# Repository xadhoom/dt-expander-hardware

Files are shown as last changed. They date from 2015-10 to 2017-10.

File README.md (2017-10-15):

## Eagle schematics and board files for Detectino hardware

These are design files for two piggy back boards used in the Detectino Alarm project.

### Detectino_nodcdc
This is an expansion board used to read analog and digital inputs from commercial
alarm sensors and provide readings over a shared CAN bus.

The core is an Arduino Nano. The board provides protection for analog
and digital signals, in order to harden Arduino inputs and a CAN bus
transceiver.

Each board can handle 8 analog sensors and 3 digital ones.

Multiple boards can be connected over a single CAN bus.

### dt-expander-v2
An updated board based on Detectino_nodcdc, where the 3 digital input have been removed,
analog inputs increased from 8 to 16, 2 relays outputs have been added, along with
6 Open Collector outputs.

To accomodate all needed I/O, the board is plugged with an Arduino Mega2650 Pro Mini:
http://wiki.epalsite.com/index.php?title=Mega2560_Pro_Mini

### Detectino_raspi
This is the "core" board, which is a piggy back for RaspberryPi B+,
which provides isolated CAN bus and isolated power supply using
a suitable DC-DC converter.

The board is completely isolated from the environment, in order
to protect the RaspberryPi where the core software runs and
avoid disruption of the service caused by external electrical factors.

This board is plugged in the same CAN bus and communicate with
the Detection expansion boards-

#### Warning!
I'm not an electronic expert at all, so I tried to understand
and do my best in designing these boards.
If someone finds any error or have suggestions, please tell!

##### Notes
The other folders are initial design of the Arduino piggy back board,
not realized in practice.

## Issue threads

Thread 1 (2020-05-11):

D_OUT/X signals overlaps

xadhoom, 2020-05-11:
Maybe an older kicad bug that messed up with D_OUT/X hierarchical labels results in D_OUT/1 and /2 mixed. Same for D_OUT/4 and 5.

Newer versions of kicad disallow `/` in label names, so that may be the cause.

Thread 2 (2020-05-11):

Check symbol / package pin assignment for Q1~Q8

xadhoom, 2020-05-11:
We messed up with package / pin assignments, so Emitter got swapped with Collector :/

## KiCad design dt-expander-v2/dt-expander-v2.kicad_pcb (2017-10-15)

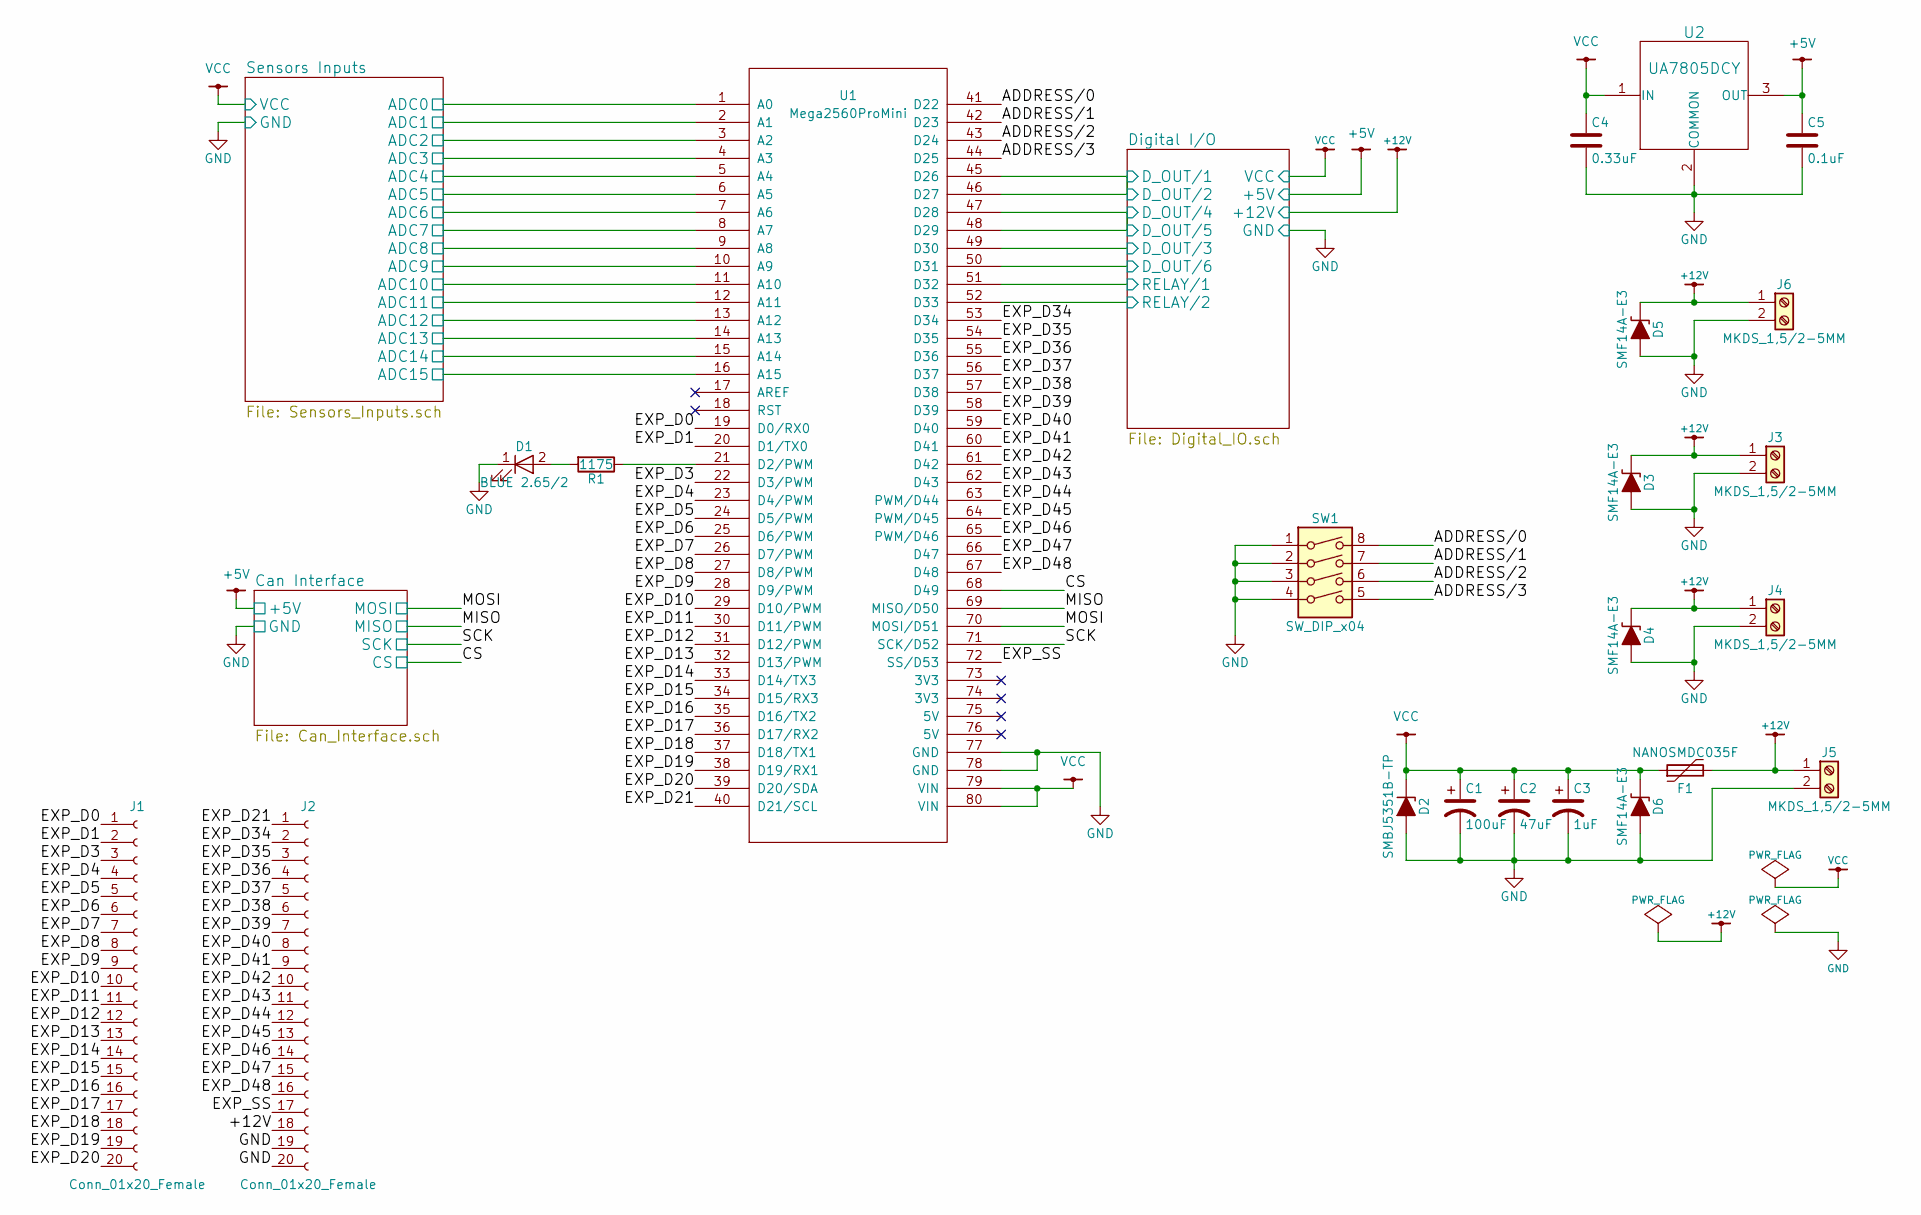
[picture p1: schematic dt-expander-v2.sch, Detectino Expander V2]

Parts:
C1: 100uF; CP_Radial_D6.3mm_P2.50mm
C2: 47uF; CP_Radial_D6.3mm_P2.50mm
C3: 1uF; CP_Radial_D4.0mm_P1.50mm
C4: 0.33uF; C_1206
C5: 0.1uF; C_1206
D1: BLUE 2.65/2; Led_1206
D2: SMBJ5351B-TP; do214aa
D3, D4, D5, D6: SMF14A-E3; do219ab
F1: NANOSMDC035F; Fuse_SMD1206_Wave
J1, J2: Conn_01x20_Female; Socket_Strip_Straight_1x20_Pitch2.54mm
J3, J4, J5, J6: MKDS_1,5/2-5MM; TerminalBlock_Pheonix_MKDS1.5-2pol
R1: 1175; R_0805
SW1: SW_DIP_x04; DIP-8_W7.62mm_LongPads
U1: Mega2560ProMini
U2: UA7805DCY; SOT-223-3Lead_TabPin2

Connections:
+5V: C5.1, U2.3 (OUT); also elsewhere on the board
+12V: D3.1 (A1), D4.1 (A1), D5.1 (A1), F1.2, J2.18, J3.1, J4.1, J5.1, J6.1; also elsewhere on the board
/ADDRESS/0: SW1.8, U1.41 (D22)
/ADDRESS/1: SW1.7, U1.42 (D23)
/ADDRESS/2: SW1.6, U1.43 (D24)
/ADDRESS/3: SW1.5, U1.44 (D25)
/CS: U1.68 (D49); also elsewhere on the board
/Digital I/O/D_OUT/1: U1.45 (D26), U1.46 (D27); also elsewhere on the board
/Digital I/O/D_OUT/3: U1.49 (D30); also elsewhere on the board
/Digital I/O/D_OUT/4: U1.47 (D28), U1.48 (D29); also elsewhere on the board
/Digital I/O/D_OUT/6: U1.50 (D31); also elsewhere on the board
/Digital I/O/RELAY/1: U1.51 (D32); also elsewhere on the board
/Digital I/O/RELAY/2: U1.52 (D33); also elsewhere on the board
/EXP_D0: J1.1, U1.19 (D0/RX0)
/EXP_D1: J1.2, U1.20 (D1/TX0)
/EXP_D3: J1.3, U1.22 (D3/PWM)
/EXP_D4: J1.4, U1.23 (D4/PWM)
/EXP_D5: J1.5, U1.24 (D5/PWM)
/EXP_D6: J1.6, U1.25 (D6/PWM)
/EXP_D7: J1.7, U1.26 (D7/PWM)
/EXP_D8: J1.8, U1.27 (D8/PWM)
/EXP_D9: J1.9, U1.28 (D9/PWM)
/EXP_D10: J1.10, U1.29 (D10/PWM)
/EXP_D11: J1.11, U1.30 (D11/PWM)
/EXP_D12: J1.12, U1.31 (D12/PWM)
/EXP_D13: J1.13, U1.32 (D13/PWM)
/EXP_D14: J1.14, U1.33 (D14/TX3)
/EXP_D15: J1.15, U1.34 (D15/RX3)
/EXP_D16: J1.16, U1.35 (D16/TX2)
/EXP_D17: J1.17, U1.36 (D17/RX2)
/EXP_D18: J1.18, U1.37 (D18/TX1)
/EXP_D19: J1.19, U1.38 (D19/RX1)
/EXP_D20: J1.20, U1.39 (D20/SDA)
/EXP_D21: J2.1, U1.40 (D21/SCL)
/EXP_D34: J2.2, U1.53 (D34)
/EXP_D35: J2.3, U1.54 (D35)
/EXP_D36: J2.4, U1.55 (D36)
/EXP_D37: J2.5, U1.56 (D37)
/EXP_D38: J2.6, U1.57 (D38)
/EXP_D39: J2.7, U1.58 (D39)
/EXP_D40: J2.8, U1.59 (D40)
/EXP_D41: J2.9, U1.60 (D41)
/EXP_D42: J2.10, U1.61 (D42)
/EXP_D43: J2.11, U1.62 (D43)
/EXP_D44: J2.12, U1.63 (PWM/D44)
/EXP_D45: J2.13, U1.64 (PWM/D45)
/EXP_D46: J2.14, U1.65 (PWM/D46)
/EXP_D47: J2.15, U1.66 (D47)
/EXP_D48: J2.16, U1.67 (D48)
/EXP_SS: J2.17, U1.72 (SS/D53)
/MISO: U1.69 (MISO/D50); also elsewhere on the board
/MOSI: U1.70 (MOSI/D51); also elsewhere on the board
/SCK: U1.71 (SCK/D52); also elsewhere on the board
/Sensors Inputs/ADC0: U1.1 (A0); also elsewhere on the board
/Sensors Inputs/ADC1: U1.2 (A1); also elsewhere on the board
/Sensors Inputs/ADC2: U1.3 (A2); also elsewhere on the board
/Sensors Inputs/ADC3: U1.4 (A3); also elsewhere on the board
/Sensors Inputs/ADC4: U1.5 (A4); also elsewhere on the board
/Sensors Inputs/ADC5: U1.6 (A5); also elsewhere on the board
/Sensors Inputs/ADC6: U1.7 (A6); also elsewhere on the board
/Sensors Inputs/ADC7: U1.8 (A7); also elsewhere on the board
/Sensors Inputs/ADC8: U1.9 (A8); also elsewhere on the board
/Sensors Inputs/ADC9: U1.10 (A9); also elsewhere on the board
/Sensors Inputs/ADC10: U1.11 (A10); also elsewhere on the board
/Sensors Inputs/ADC11: U1.12 (A11); also elsewhere on the board
/Sensors Inputs/ADC12: U1.13 (A12); also elsewhere on the board
/Sensors Inputs/ADC13: U1.14 (A13); also elsewhere on the board
/Sensors Inputs/ADC14: U1.15 (A14); also elsewhere on the board
/Sensors Inputs/ADC15: U1.16 (A15); also elsewhere on the board
GND: C1.2, C2.2, C3.2, C4.2, C5.2, D1.1 (K), D2.2 (A), D3.2 (A2), D4.2 (A2), D5.2 (A2), D6.2 (A2), J2.19, J2.20, J3.2, J4.2, J5.2, J6.2, SW1.1, SW1.2, SW1.3, SW1.4, U1.77 (GND), U1.78 (GND), U2.2 (COMMON); also elsewhere on the board
unnamed: D1.2 (A), R1.2
unnamed: R1.1, U1.21 (D2/PWM)
VCC: C1.1, C2.1, C3.1, C4.1, D2.1 (K), D6.1 (A1), F1.1, U1.79 (VIN), U1.80 (VIN), U2.1 (IN); also elsewhere on the board

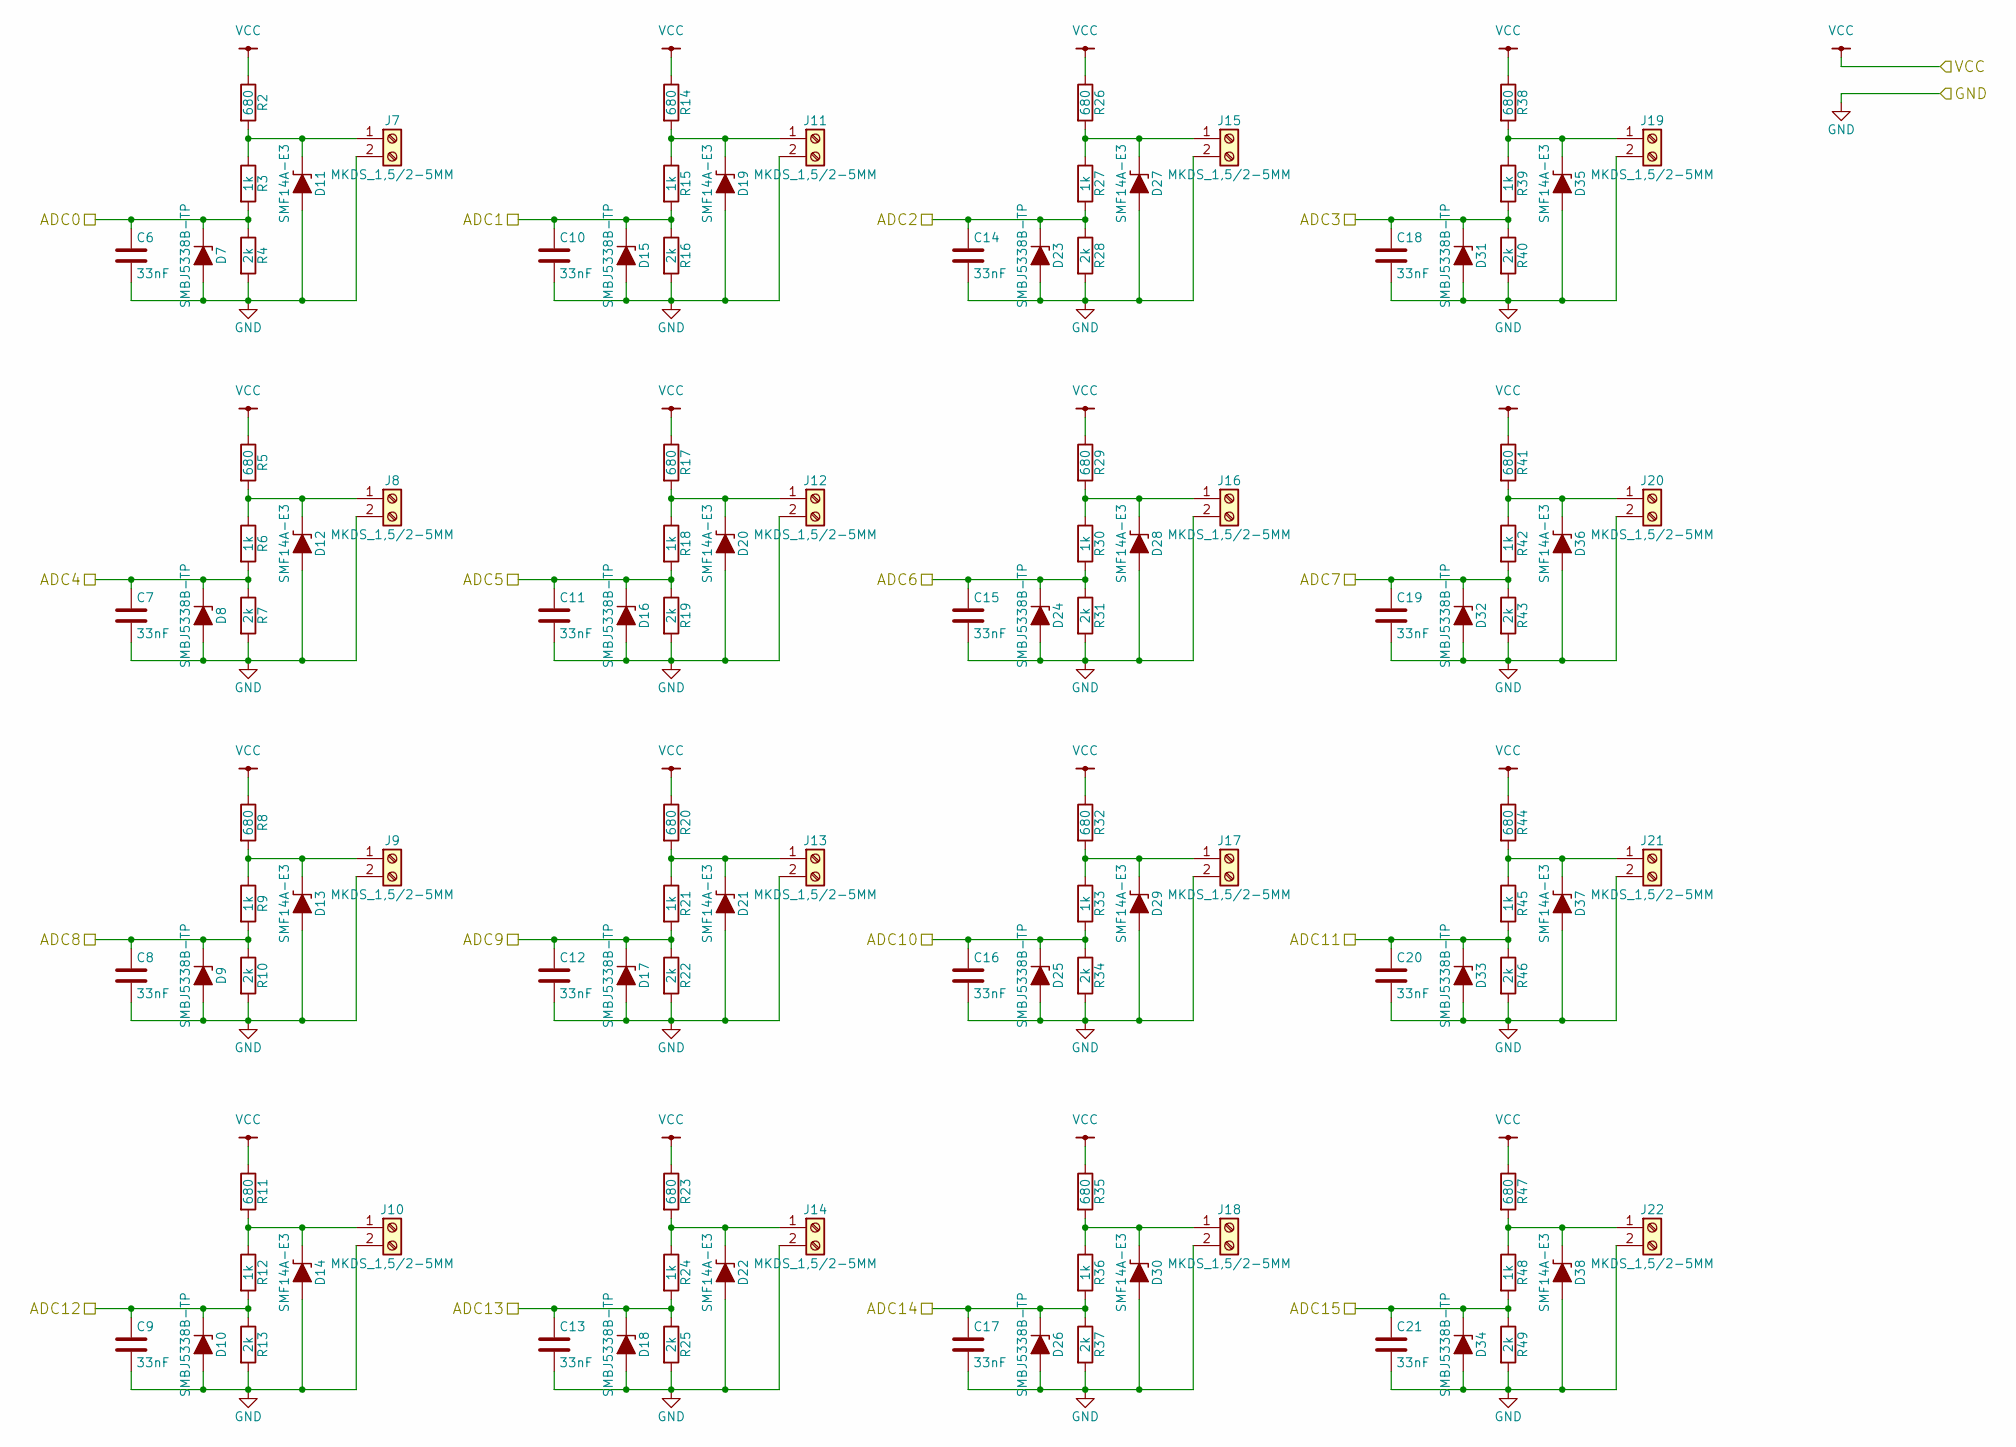
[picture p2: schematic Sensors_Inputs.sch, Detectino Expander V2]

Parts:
C6, C7, C8, C9, C10, C11, C12, C13, C14, C15, C16, C17, C18, C19, C20, C21: 33nF; C_1206
D7, D8, D9, D10, D15, D16, D17, D18, D23, D24, D25, D26, D31, D32, D33, D34: SMBJ5338B-TP; do214aa
D11, D12, D13, D14, D19, D20, D21, D22, D27, D28, D29, D30, D35, D36, D37, D38: SMF14A-E3; do219ab
J7, J8, J9, J10, J11, J12, J13, J14, J15, J16, J17, J18, J19, J20, J21, J22: MKDS_1,5/2-5MM; TerminalBlock_Pheonix_MKDS1.5-2pol
R2, R5, R8, R11, R14, R17, R20, R23, R26, R29, R32, R35, R38, R41, R44, R47: 680; R_0805
R3, R6, R9, R12, R15, R18, R21, R24, R27, R30, R33, R36, R39, R42, R45, R48: 1k; R_0805
R4, R7, R10, R13, R16, R19, R22, R25, R28, R31, R34, R37, R40, R43, R46, R49: 2k; R_0805

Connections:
/Sensors Inputs/ADC0: C6.1, D7.1 (K), R3.2, R4.1; also elsewhere on the board
/Sensors Inputs/ADC1: C10.1, D15.1 (K), R15.2, R16.1; also elsewhere on the board
/Sensors Inputs/ADC2: C14.1, D23.1 (K), R27.2, R28.1; also elsewhere on the board
/Sensors Inputs/ADC3: C18.1, D31.1 (K), R39.2, R40.1; also elsewhere on the board
/Sensors Inputs/ADC4: C7.1, D8.1 (K), R6.2, R7.1; also elsewhere on the board
/Sensors Inputs/ADC5: C11.1, D16.1 (K), R18.2, R19.1; also elsewhere on the board
/Sensors Inputs/ADC6: C15.1, D24.1 (K), R30.2, R31.1; also elsewhere on the board
/Sensors Inputs/ADC7: C19.1, D32.1 (K), R42.2, R43.1; also elsewhere on the board
/Sensors Inputs/ADC8: C8.1, D9.1 (K), R9.2, R10.1; also elsewhere on the board
/Sensors Inputs/ADC9: C12.1, D17.1 (K), R21.2, R22.1; also elsewhere on the board
/Sensors Inputs/ADC10: C16.1, D25.1 (K), R33.2, R34.1; also elsewhere on the board
/Sensors Inputs/ADC11: C20.1, D33.1 (K), R45.2, R46.1; also elsewhere on the board
/Sensors Inputs/ADC12: C9.1, D10.1 (K), R12.2, R13.1; also elsewhere on the board
/Sensors Inputs/ADC13: C13.1, D18.1 (K), R24.2, R25.1; also elsewhere on the board
/Sensors Inputs/ADC14: C17.1, D26.1 (K), R36.2, R37.1; also elsewhere on the board
/Sensors Inputs/ADC15: C21.1, D34.1 (K), R48.2, R49.1; also elsewhere on the board
GND: C6.2, C7.2, C8.2, C9.2, C10.2, C11.2, C12.2, C13.2, C14.2, C15.2, C16.2, C17.2, C18.2, C19.2, C20.2, C21.2, D7.2 (A), D8.2 (A), D9.2 (A), D10.2 (A), D11.2 (A2), D12.2 (A2), D13.2 (A2), D14.2 (A2), D15.2 (A), D16.2 (A), D17.2 (A), D18.2 (A), D19.2 (A2), D20.2 (A2), D21.2 (A2), D22.2 (A2), D23.2 (A), D24.2 (A), D25.2 (A), D26.2 (A), D27.2 (A2), D28.2 (A2), D29.2 (A2), D30.2 (A2), D31.2 (A), D32.2 (A), D33.2 (A), D34.2 (A), D35.2 (A2), D36.2 (A2), D37.2 (A2), D38.2 (A2), J7.2, J8.2, J9.2, J10.2, J11.2, J12.2, J13.2, J14.2, J15.2, J16.2, J17.2, J18.2, J19.2, J20.2, J21.2, J22.2, R4.2, R7.2, R10.2, R13.2, R16.2, R19.2, R22.2, R25.2, R28.2, R31.2, R34.2, R37.2, R40.2, R43.2, R46.2, R49.2; also elsewhere on the board
unnamed 82: D11.1 (A1), J7.1, R2.2, R3.1; also elsewhere on the board
unnamed 83: D12.1 (A1), J8.1, R5.2, R6.1; also elsewhere on the board
unnamed 84: D13.1 (A1), J9.1, R8.2, R9.1; also elsewhere on the board
unnamed 85: D14.1 (A1), J10.1, R11.2, R12.1; also elsewhere on the board
unnamed 86: D19.1 (A1), J11.1, R14.2, R15.1; also elsewhere on the board
unnamed 87: D20.1 (A1), J12.1, R17.2, R18.1; also elsewhere on the board
unnamed 88: D21.1 (A1), J13.1, R20.2, R21.1; also elsewhere on the board
unnamed 89: D22.1 (A1), J14.1, R23.2, R24.1; also elsewhere on the board
unnamed 90: D27.1 (A1), J15.1, R26.2, R27.1; also elsewhere on the board
unnamed 91: D28.1 (A1), J16.1, R29.2, R30.1; also elsewhere on the board
unnamed 92: D29.1 (A1), J17.1, R32.2, R33.1; also elsewhere on the board
unnamed 93: D30.1 (A1), J18.1, R35.2, R36.1; also elsewhere on the board
unnamed 94: D35.1 (A1), J19.1, R38.2, R39.1; also elsewhere on the board
unnamed 95: D36.1 (A1), J20.1, R41.2, R42.1; also elsewhere on the board
unnamed 96: D37.1 (A1), J21.1, R44.2, R45.1; also elsewhere on the board
unnamed 97: D38.1 (A1), J22.1, R47.2, R48.1; also elsewhere on the board
VCC: R2.1, R5.1, R8.1, R11.1, R14.1, R17.1, R20.1, R23.1, R26.1, R29.1, R32.1, R35.1, R38.1, R41.1, R44.1, R47.1; also elsewhere on the board

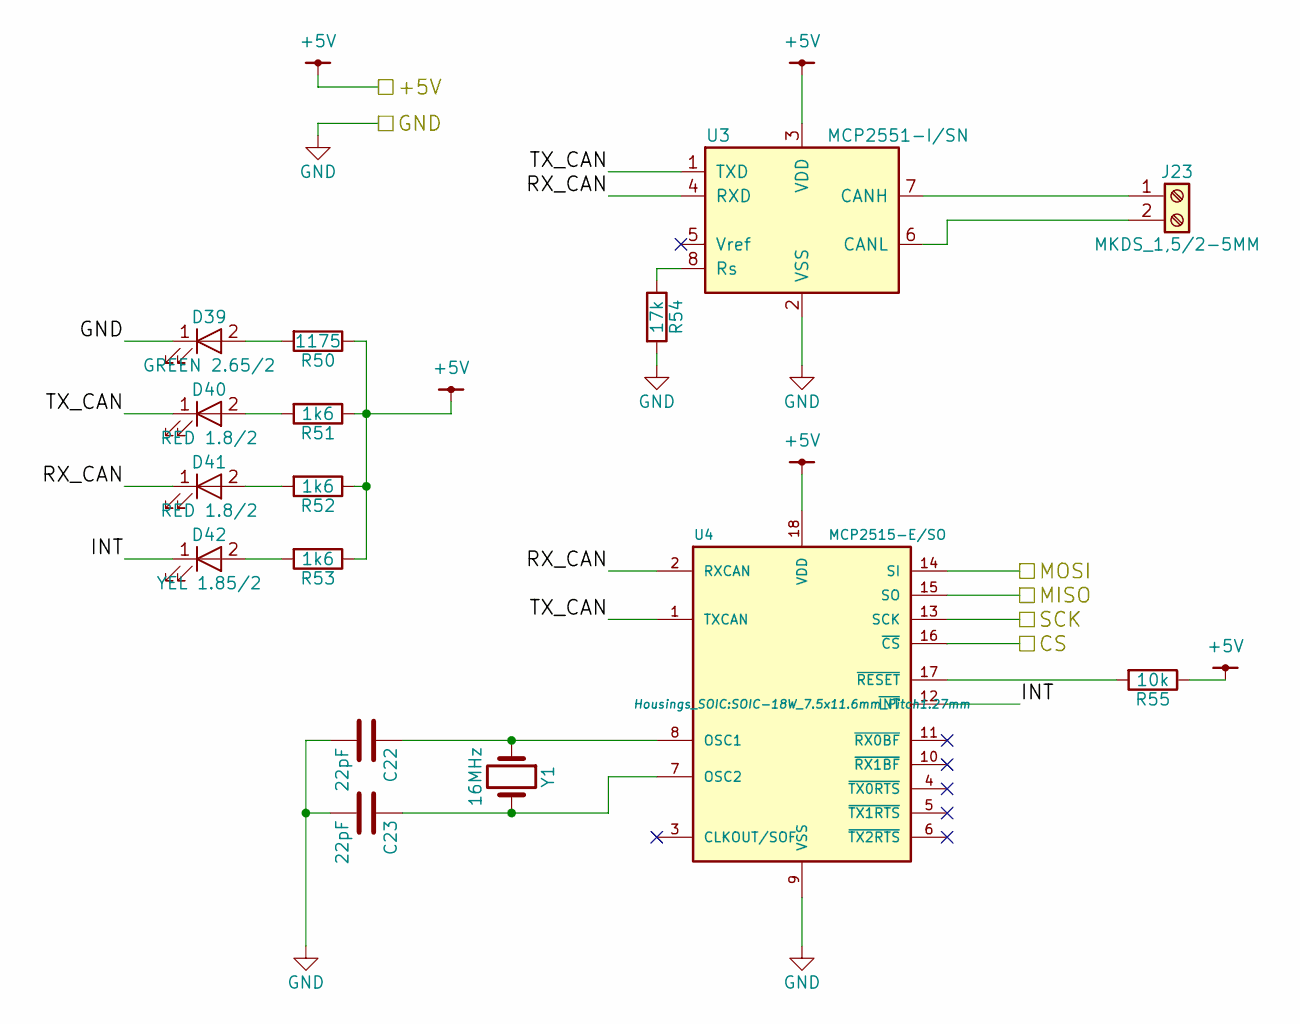
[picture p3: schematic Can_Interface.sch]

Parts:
C22, C23: 22pF; C_1206
D39: GREEN 2.65/2; Led_1206
D40, D41: RED 1.8/2; Led_1206
D42: YEL 1.85/2; Led_1206
J23: MKDS_1,5/2-5MM; TerminalBlock_Pheonix_MKDS1.5-2pol
R50: 1175; R_0805
R51, R52, R53: 1k6; R_0805
R54: 17k; R_0805
R55: 10k; R_0805
U3: MCP2551-I/SN; SOIC-8_3.9x4.9mm_Pitch1.27mm
U4: MCP2515-E/SO; SOIC-18W_7.5x11.6mm_Pitch1.27mm
Y1: 16MHz; Crystal_HC49-U_Vertical

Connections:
+5V: R50.1, R51.1, R52.1, R53.1, R55.1, U3.3 (VDD), U4.18 (VDD); also elsewhere on the board
/CS: U4.16 (~CS~); also elsewhere on the board
/Can Interface/INT: D42.1 (K), U4.12 (~INT~)
/Can Interface/RX_CAN: D41.1 (K), U3.4 (RXD), U4.2 (RXCAN)
/Can Interface/TX_CAN: D40.1 (K), U3.1 (TXD), U4.1 (TXCAN)
/MISO: U4.15 (SO); also elsewhere on the board
/MOSI: U4.14 (SI); also elsewhere on the board
/SCK: U4.13 (SCK); also elsewhere on the board
GND: C22.2, C23.2, D39.1 (K), R54.2, U3.2 (VSS), U4.9 (VSS); also elsewhere on the board
unnamed: C22.1, U4.8 (OSC1), Y1.1
unnamed: C23.1, U4.7 (OSC2), Y1.2
unnamed: D39.2 (A), R50.2
unnamed: D40.2 (A), R51.2
unnamed: D41.2 (A), R52.2
unnamed: D42.2 (A), R53.2
unnamed: J23.1, U3.7 (CANH)
unnamed: J23.2, U3.6 (CANL)
unnamed: R54.1, U3.8 (Rs)
unnamed: R55.2, U4.17 (~RESET~)

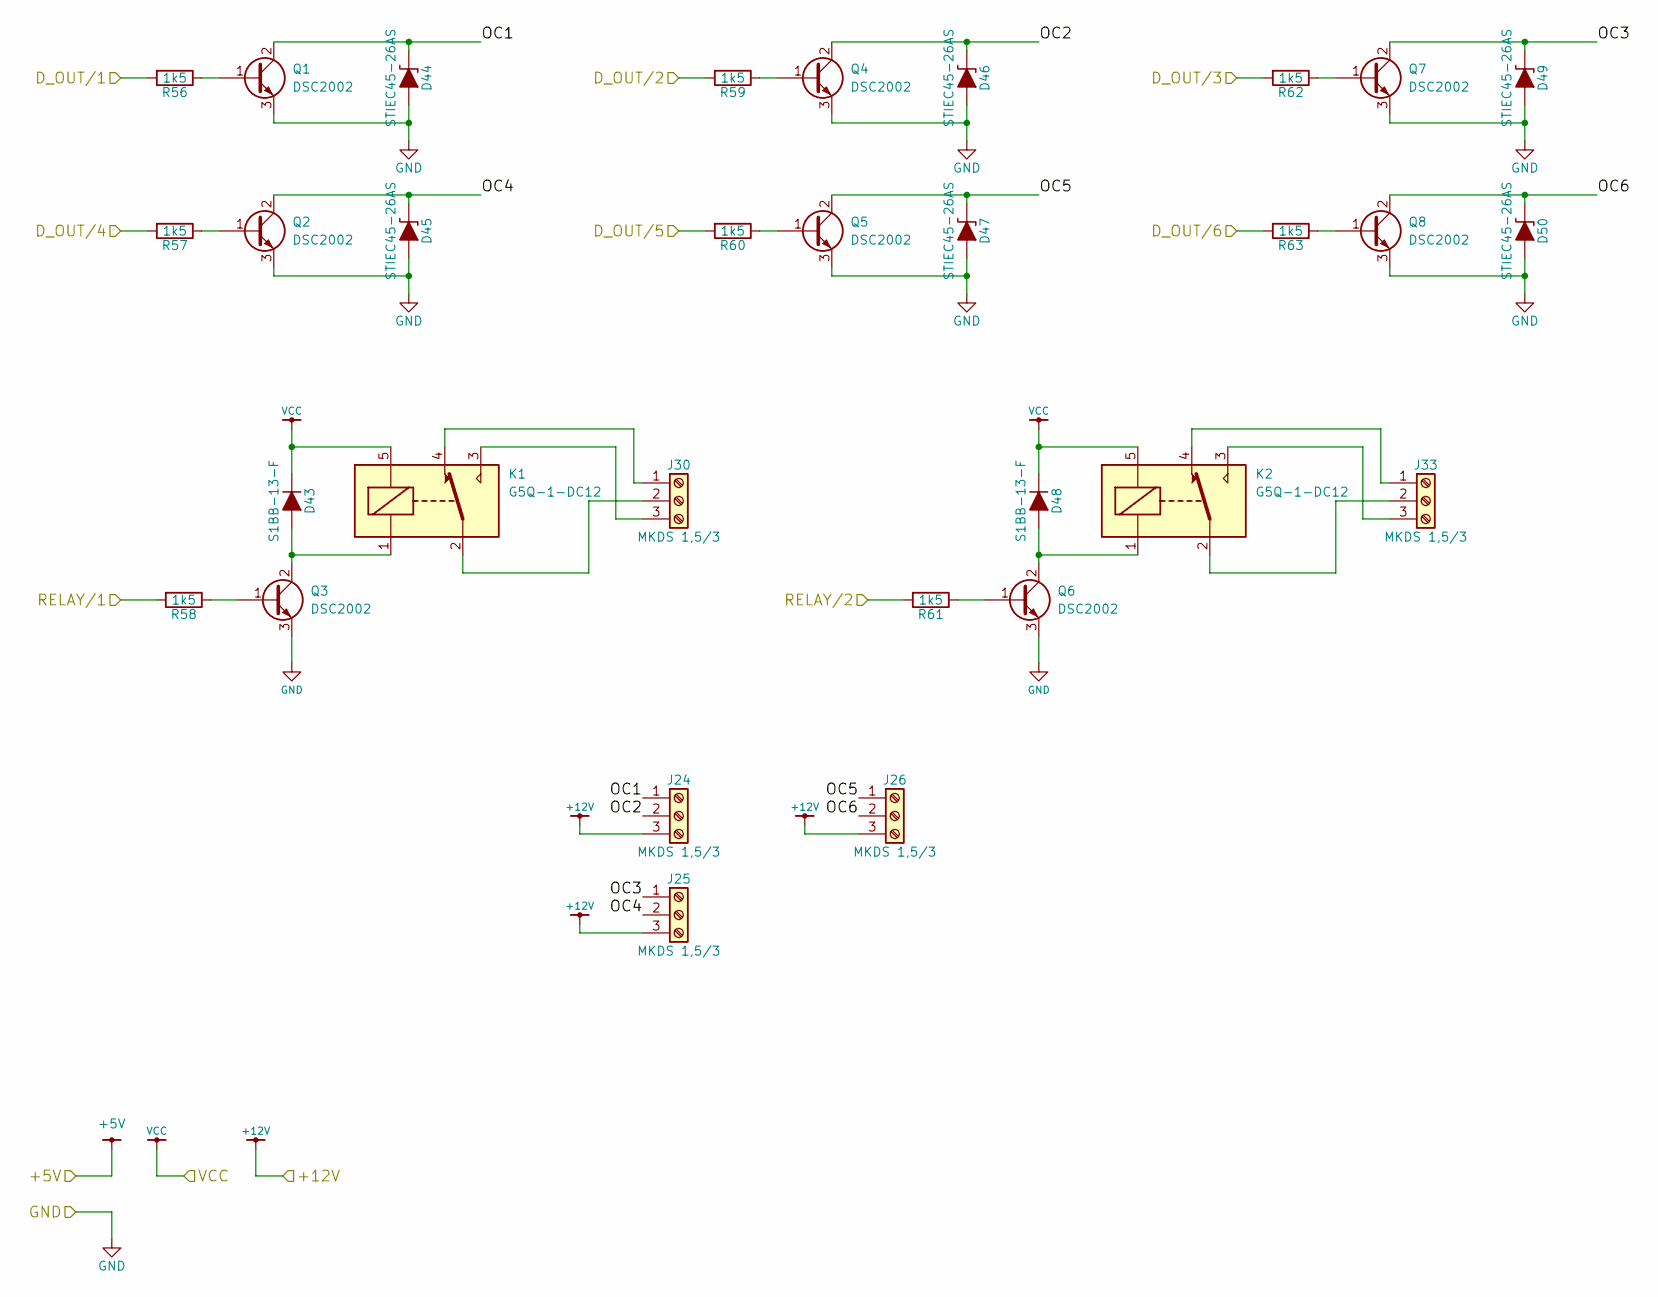
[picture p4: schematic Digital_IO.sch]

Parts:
D43, D48: S1BB-13-F; do214aa
D44, D45, D46, D47, D49, D50: STIEC45-26AS; do214ab
J24, J25, J26, J30, J33: MKDS 1,5/3; TerminalBlock_Pheonix_MKDS1.5-3pol
K1, K2: G5Q-1-DC12; Relay_SPDT_OMRON-G5Q
Q1, Q2, Q3, Q4, Q5, Q6, Q7, Q8: DSC2002; SOT-23
R56, R57, R58, R59, R60, R61, R62, R63: 1k5; R_0805

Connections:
+12V: J24.3, J25.3, J26.3; also elsewhere on the board
/Digital I/O/D_OUT/1: R56.2, R59.2; also elsewhere on the board
/Digital I/O/D_OUT/3: R62.2; also elsewhere on the board
/Digital I/O/D_OUT/4: R57.2, R60.2; also elsewhere on the board
/Digital I/O/D_OUT/6: R63.2; also elsewhere on the board
/Digital I/O/OC1: D44.1 (A1), J24.1, Q1.2 (C)
/Digital I/O/OC2: D46.1 (A1), J24.2, Q4.2 (C)
/Digital I/O/OC3: D49.1 (A1), J25.1, Q7.2 (C)
/Digital I/O/OC4: D45.1 (A1), J25.2, Q2.2 (C)
/Digital I/O/OC5: D47.1 (A1), J26.1, Q5.2 (C)
/Digital I/O/OC6: D50.1 (A1), J26.2, Q8.2 (C)
/Digital I/O/RELAY/1: R58.2; also elsewhere on the board
/Digital I/O/RELAY/2: R61.2; also elsewhere on the board
GND: D44.2 (A2), D45.2 (A2), D46.2 (A2), D47.2 (A2), D49.2 (A2), D50.2 (A2), Q1.3 (E), Q2.3 (E), Q3.3 (E), Q4.3 (E), Q5.3 (E), Q6.3 (E), Q7.3 (E), Q8.3 (E); also elsewhere on the board
unnamed: D43.2 (A), K1.1, Q3.2 (C)
unnamed: D48.2 (A), K2.1, Q6.2 (C)
unnamed: J30.1, K1.4
unnamed: J30.2, K1.2
unnamed: J30.3, K1.3
unnamed: J33.1, K2.4
unnamed: J33.2, K2.2
unnamed: J33.3, K2.3
unnamed: Q1.1 (B), R56.1
unnamed: Q2.1 (B), R57.1
unnamed: Q3.1 (B), R58.1
unnamed: Q4.1 (B), R59.1
unnamed: Q5.1 (B), R60.1
unnamed: Q6.1 (B), R61.1
unnamed: Q7.1 (B), R62.1
unnamed: Q8.1 (B), R63.1
VCC: D43.1 (K), D48.1 (K), K1.5, K2.5; also elsewhere on the board

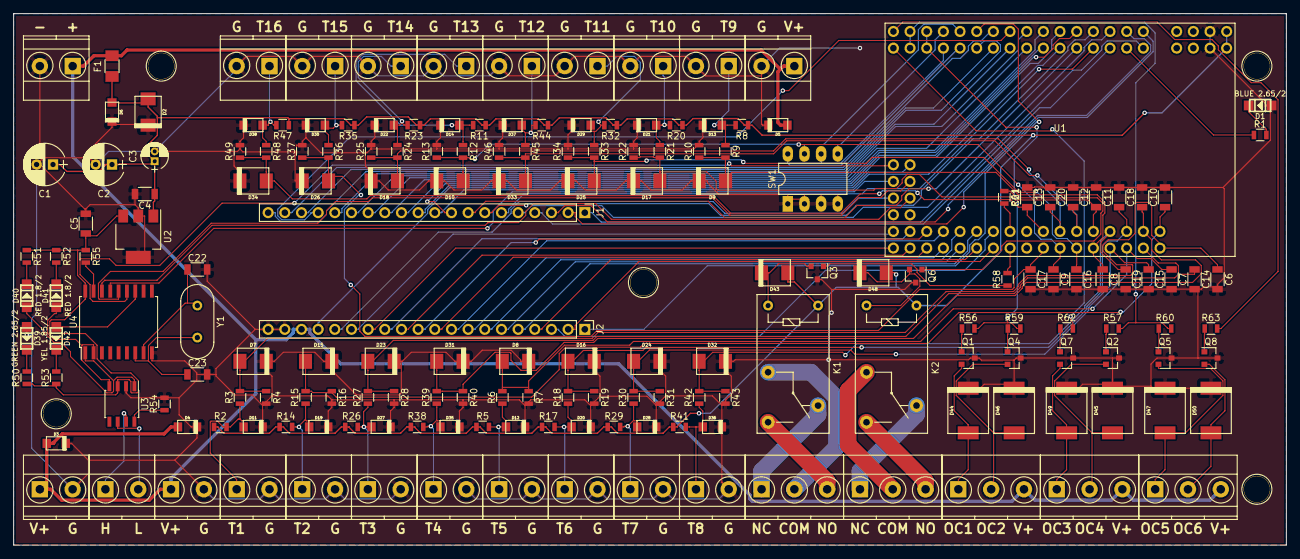
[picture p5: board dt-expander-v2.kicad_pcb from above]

Board: 2 copper layers, 194.0 x 81.0 mm, 185 parts (0 on the bottom side), 124 nets.

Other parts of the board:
HOLE1, HOLE2, HOLE3, HOLE4: 1pin
T1, T2, T3, T4, T5, T6, T7, T8, T9, T10, T11, T12, T13, T14, T15, T16: MKDS_1,5/2-5MM; TerminalBlock_Pheonix_MKDS1.5-2pol

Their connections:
GND: T1.2, T2.2, T3.2, T4.2, T5.2, T6.2, T7.2, T8.2, T9.2, T10.2, T11.2, T12.2, T13.2, T14.2, T15.2, T16.2; also elsewhere on the board
unnamed 82: T1.1; also elsewhere on the board
unnamed 83: T5.1; also elsewhere on the board
unnamed 84: T9.1; also elsewhere on the board
unnamed 85: T13.1; also elsewhere on the board
unnamed 86: T2.1; also elsewhere on the board
unnamed 87: T6.1; also elsewhere on the board
unnamed 88: T10.1; also elsewhere on the board
unnamed 89: T14.1; also elsewhere on the board
unnamed 90: T3.1; also elsewhere on the board
unnamed 91: T7.1; also elsewhere on the board
unnamed 92: T11.1; also elsewhere on the board
unnamed 93: T15.1; also elsewhere on the board
unnamed 94: T4.1; also elsewhere on the board
unnamed 95: T8.1; also elsewhere on the board
unnamed 96: T12.1; also elsewhere on the board
unnamed 97: T16.1; also elsewhere on the board

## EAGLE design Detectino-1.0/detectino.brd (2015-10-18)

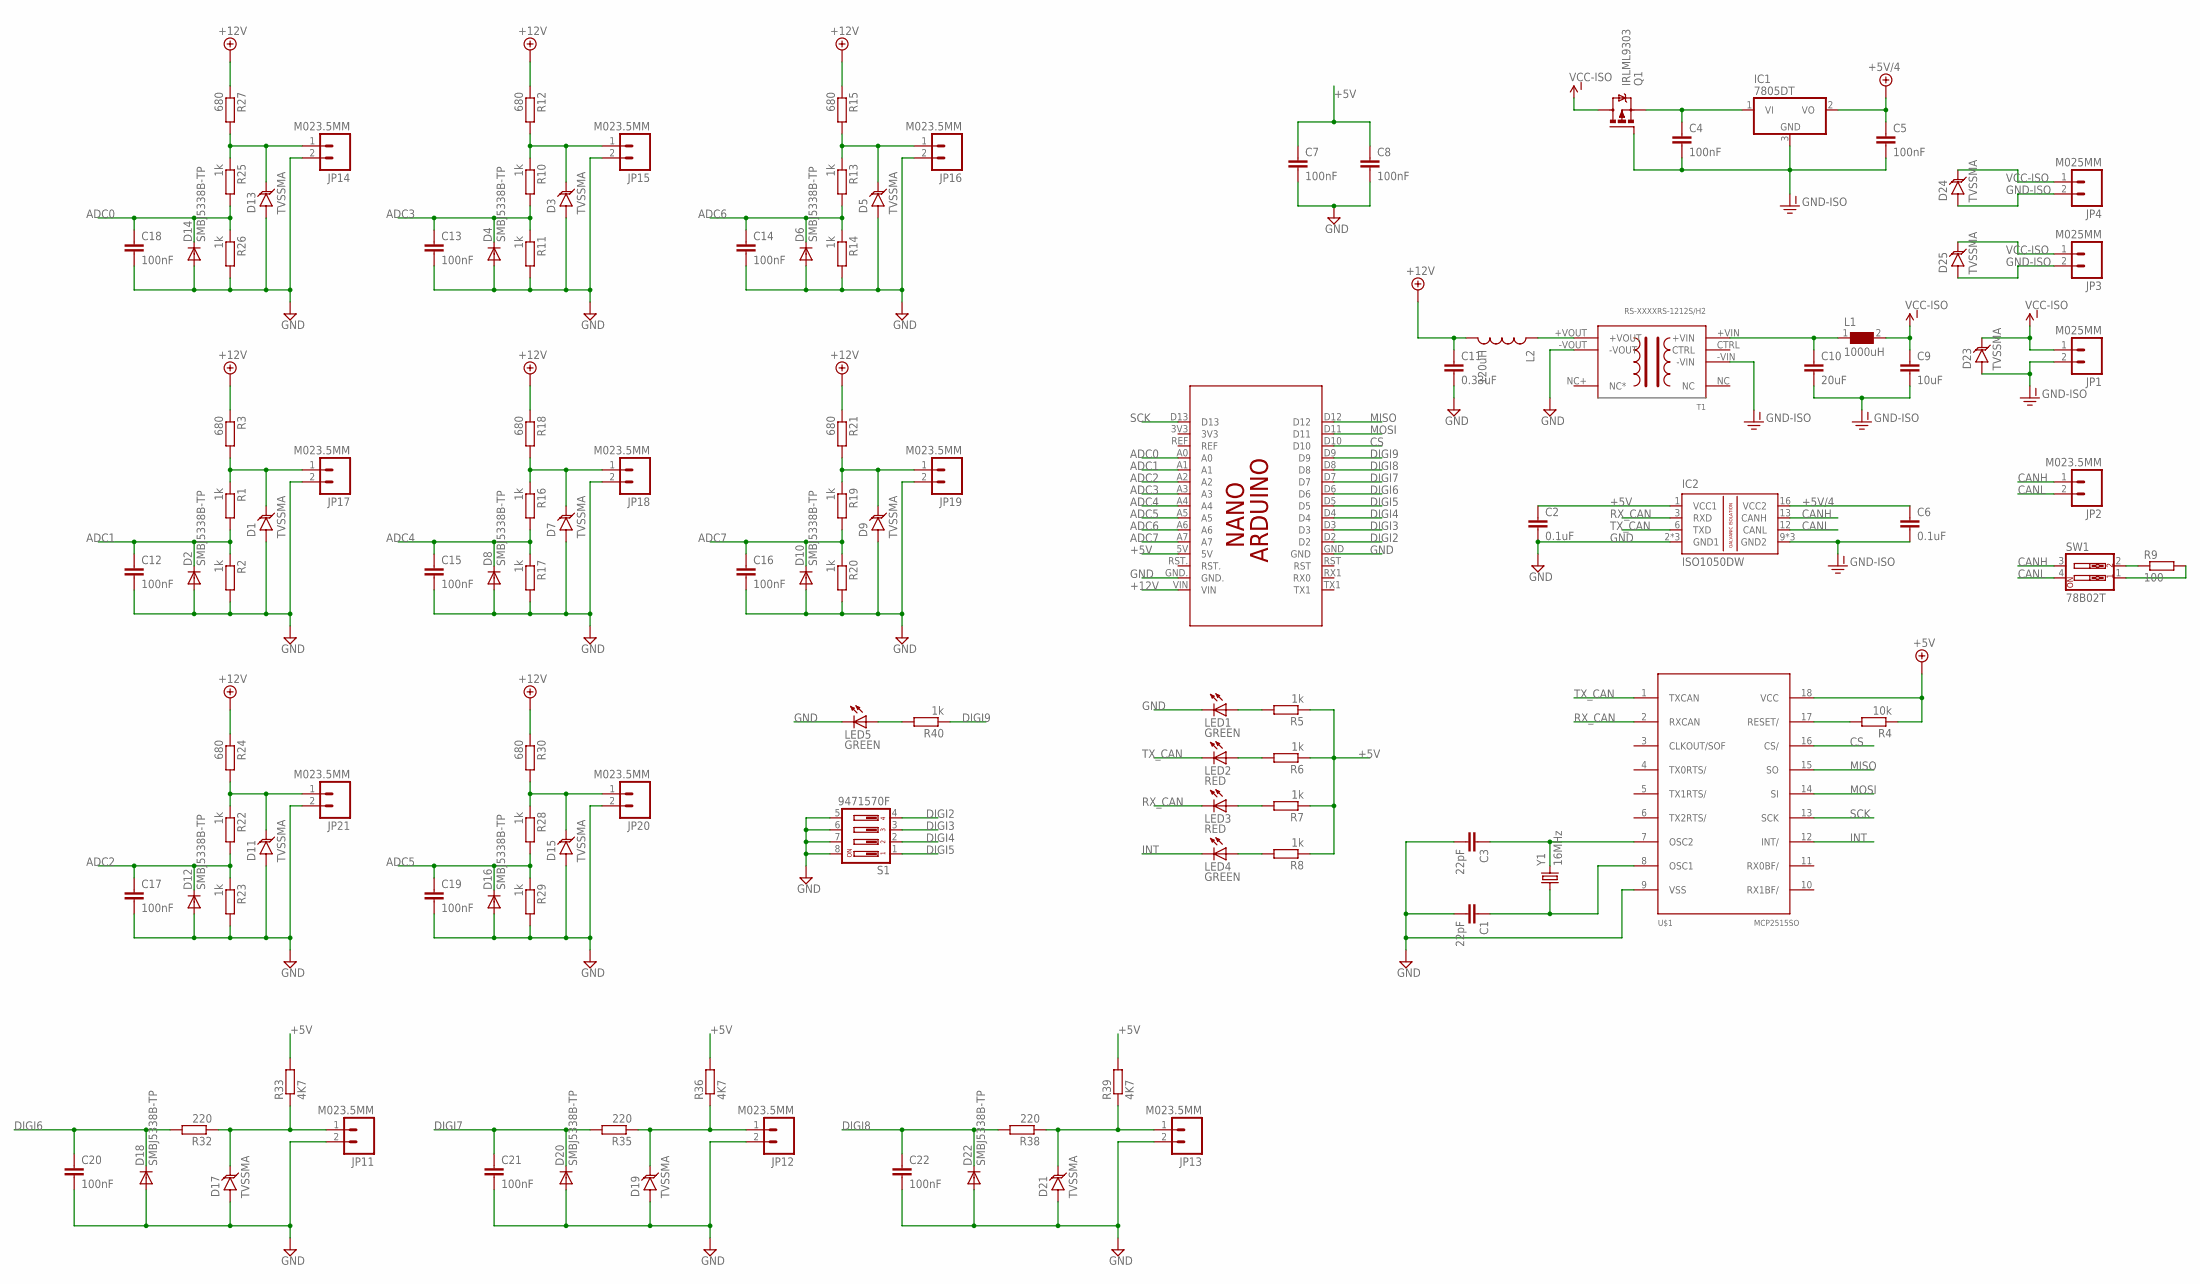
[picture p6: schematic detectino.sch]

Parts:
C1, C3: 22pF; C0805K
C2, C6: 0.1uF; C0805K
C4, C5, C7, C8, C12, C13, C14, C15, C16, C17, C18, C19, C20, C21, C22: 100nF; C0805K
C9: 10uF; C0805K
C10: 20uF; C0805K
C11: 0.33uF; C0805K
D1, D3, D5, D7, D9, D11, D13, D15, D17, D19, D21, D23, D24, D25: TVSSMA; SMA-DIODE
D2, D4, D6, D8, D10, D12, D14, D16, D18, D20, D22: SMBJ5338B-TP; DO214AA
IC1: 7805DT; TO252
IC2: ISO1050DW; SO-16DW
JP1, JP3, JP4: M025MM; SCREWTERMINAL-5MM-2
JP2, JP11, JP12, JP13, JP14, JP15, JP16, JP17, JP18, JP19, JP20, JP21: M023.5MM; SCREWTERMINAL-3.5MM-2
L1: 1000uH; WE-TIS_1111
L2: 120uH; SDR0403
LED1, LED4, LED5: GREEN; SML0805
LED2, LED3: RED; SML0805
PCB2: ARDUINO_NANO
Q1: IRLML9303; MICRO3
R1, R2, R5, R6, R7, R8, R10, R11, R13, R14, R16, R17, R19, R20, R22, R23, R25, R26, R28, R29, R40: 1k; 0204/5
R3, R12, R15, R18, R21, R24, R27, R30: 680; 0204/5
R4: 10k; R0805W
R9: 100; R0805W
R32, R35, R38: 220; 0204/5
R33, R36, R39: 4K7; 0204/5
S1: 9471570F; DS-04
SW1: 78B02T; DIPSWITCH-02
T1: RS-XXXXRS-1212S/H2; SIP8
U$1: MCP2515SO; SO18L
Y1: 16MHz; HC49US

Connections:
+5V: C2.1, C7.1, C8.1, IC2.1 (VCC1), PCB2.5V, R4.1, R5.1, R6.1, R7.1, R8.1, R33.2, R36.2, R39.2, U$1.18 (VCC)
+5V/4: C5.1, C6.1, IC1.2 (VO), IC2.16 (VCC2)
+12V: C11.1, L2.P$2 (2), PCB2.VIN, R3.1, R12.1, R15.1, R18.1, R21.1, R24.1, R27.1, R30.1
ADC0: C18.1, D14.C, PCB2.A0, R25.2, R26.1
ADC1: C12.1, D2.C, PCB2.A1, R1.2, R2.1
ADC2: C17.1, D12.C, PCB2.A2, R22.2, R23.1
ADC3: C13.1, D4.C, PCB2.A3, R10.2, R11.1
ADC4: C15.1, D8.C, PCB2.A4, R16.2, R17.1
ADC5: C19.1, D16.C, PCB2.A5, R28.2, R29.1
ADC6: C14.1, D6.C, PCB2.A6, R13.2, R14.1
ADC7: C16.1, D10.C, PCB2.A7, R19.2, R20.1
CANH: IC2.13 (CANH), JP2.1, SW1.3
CANL: IC2.12 (CANL), JP2.2, SW1.4
CS: PCB2.D10, U$1.16 (CS/)
DIGI2: PCB2.D2, S1.4
DIGI3: PCB2.D3, S1.3
DIGI4: PCB2.D4, S1.2
DIGI5: PCB2.D5, S1.1
DIGI6: C20.1, D18.C, PCB2.D6, R32.2
DIGI7: C21.1, D20.C, PCB2.D7, R35.2
DIGI8: C22.1, D22.C, PCB2.D8, R38.2
DIGI9: PCB2.D9, R40.1
GND: C1.2, C2.2, C3.2, C7.2, C8.2, C11.2, C12.2, C13.2, C14.2, C15.2, C16.2, C17.2, C18.2, C19.2, C20.2, C21.2, C22.2, D1.A, D2.A, D3.A, D4.A, D5.A, D6.A, D7.A, D8.A, D9.A, D10.A, D11.A, D12.A, D13.A, D14.A, D15.A, D16.A, D17.A, D18.A, D19.A, D20.A, D21.A, D22.A, IC2.2 (GND1), IC2.7 (GND1), IC2.8 (GND1), JP11.2, JP12.2, JP13.2, JP14.2, JP15.2, JP16.2, JP17.2, JP18.2, JP19.2, JP20.2, JP21.2, LED1.C, LED5.C, PCB2.GND, PCB2.GND., R2.2, R11.2, R14.2, R17.2, R20.2, R23.2, R26.2, R29.2, S1.5, S1.6, S1.7, S1.8, T1.-VOUT, U$1.9 (VSS)
GND-ISO: C4.2, C5.2, C6.2, C9.2, C10.2, D23.A, D24.A, D25.A, IC1.3 (GND), IC2.9 (GND2), IC2.10 (GND2), IC2.15 (GND2), JP1.2, JP3.2, JP4.2, Q1.1 (G), T1.-VIN
INT: LED4.C, U$1.12 (INT/)
MISO: PCB2.D12, U$1.15 (SO)
MOSI: PCB2.D11, U$1.14 (SI)
unnamed: D1.C, JP17.1, R1.1, R3.2
unnamed: R4.2, U$1.17 (RESET/)
unnamed: C1.1, U$1.8 (OSC1), Y1.1
unnamed: C3.1, U$1.7 (OSC2), Y1.2
unnamed: C4.1, IC1.1 (VI), Q1.2 (S)
unnamed: LED1.A, R5.2
unnamed: LED2.A, R6.2
unnamed: LED3.A, R7.2
unnamed: LED4.A, R8.2
unnamed: C10.1, L1.1, T1.+VIN
unnamed: R9.1, SW1.2
unnamed: R9.2, SW1.1
unnamed: D3.C, JP15.1, R10.1, R12.2
unnamed: D5.C, JP16.1, R13.1, R15.2
unnamed: D7.C, JP18.1, R16.1, R18.2
unnamed: D9.C, JP19.1, R19.1, R21.2
unnamed: D11.C, JP21.1, R22.1, R24.2
unnamed: D13.C, JP14.1, R25.1, R27.2
unnamed: D15.C, JP20.1, R28.1, R30.2
unnamed: L2.P$1 (1), T1.+VOUT
unnamed: D17.C, JP11.1, R32.1, R33.1
unnamed: D19.C, JP12.1, R35.1, R36.1
unnamed: D21.C, JP13.1, R38.1, R39.1
unnamed: LED5.A, R40.2
RX_CAN: IC2.3 (RXD), LED3.C, U$1.2 (RXCAN)
SCK: PCB2.D13, U$1.13 (SCK)
TX_CAN: IC2.6 (TXD), LED2.C, U$1.1 (TXCAN)
VCC-ISO: C9.1, D23.C, D24.C, D25.C, JP1.1, JP3.1, JP4.1, L1.2, Q1.3 (D)

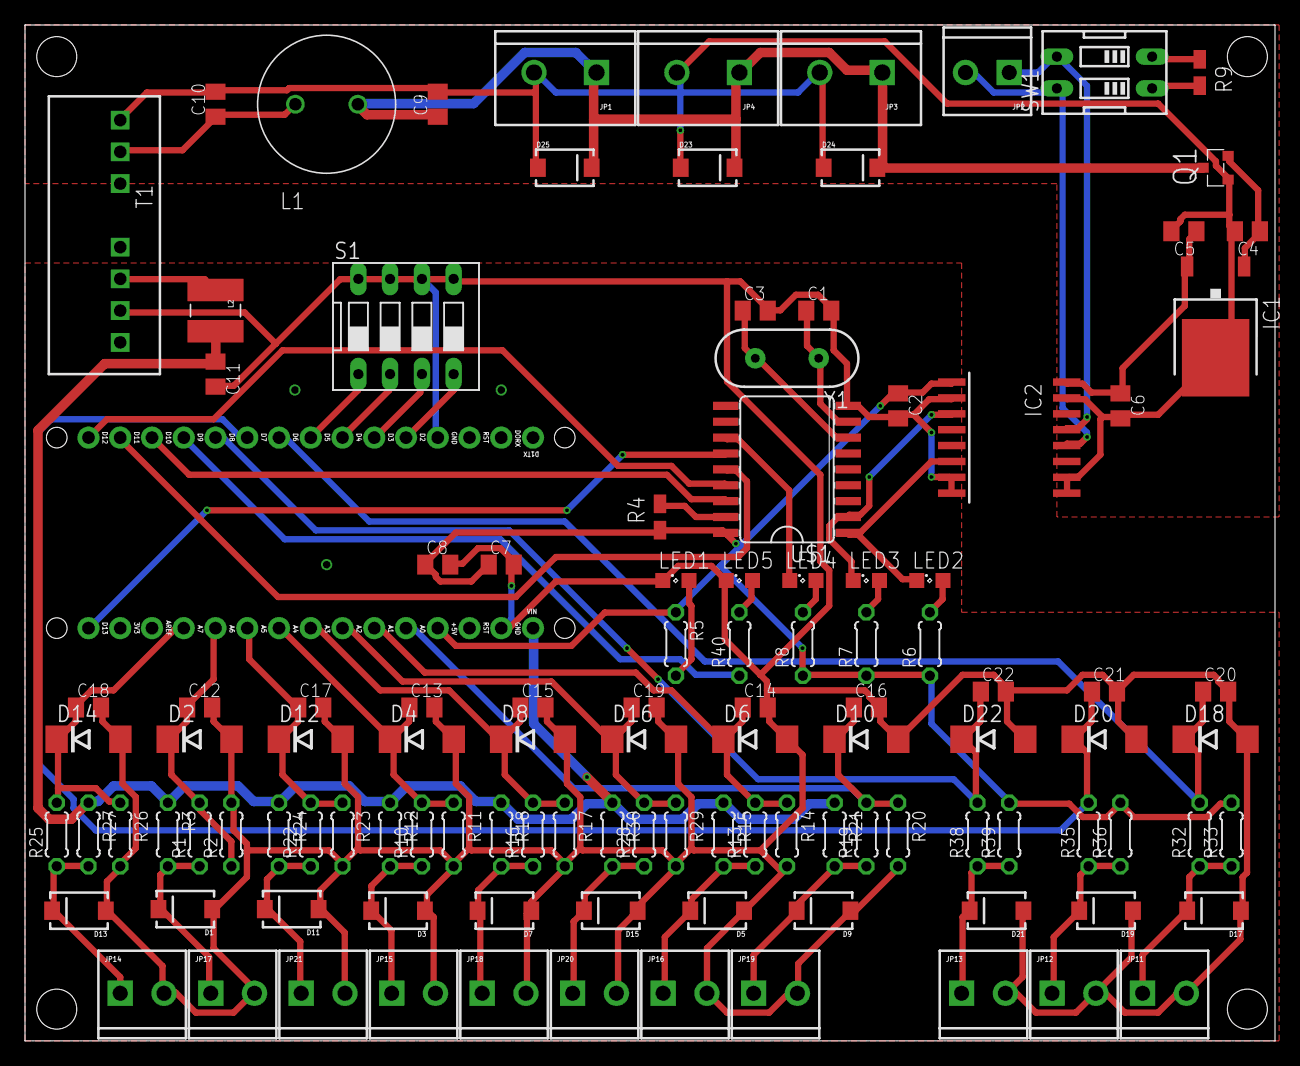
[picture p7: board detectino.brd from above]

Board: 2 copper layers, 100.0 x 81.3 mm, 115 parts (0 on the bottom side), 55 nets.

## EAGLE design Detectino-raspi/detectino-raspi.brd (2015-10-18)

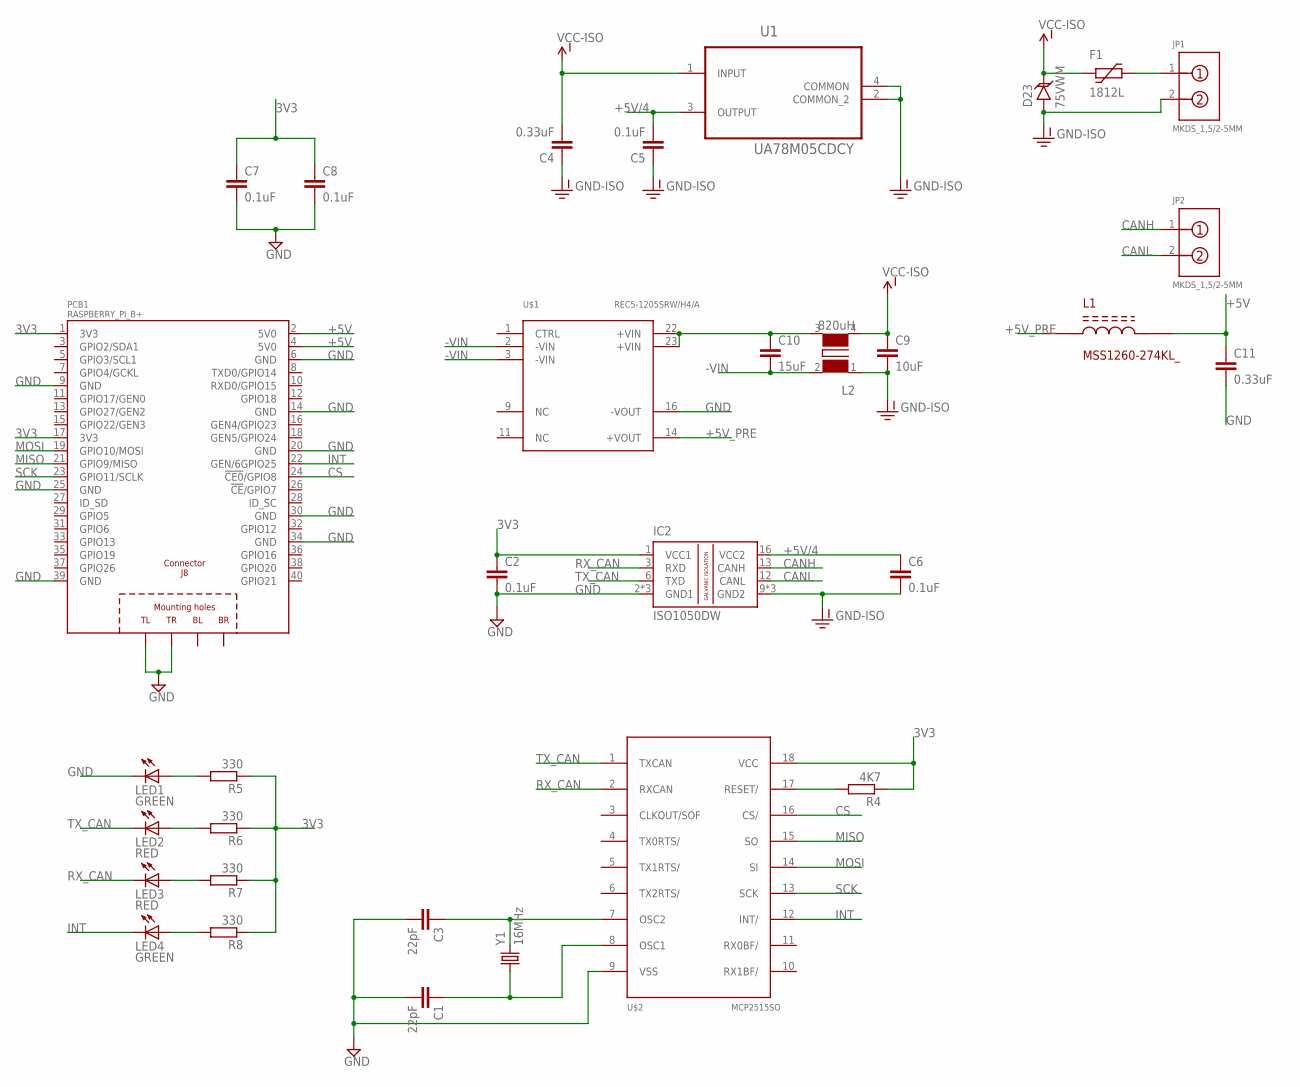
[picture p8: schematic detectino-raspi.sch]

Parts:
C1, C3: 22pF; C1206K
C2, C5, C6, C7, C8: 0.1uF; C1206K
C4, C11: 0.33uF; C1206K
C9: 10uF; C1812K
C10: 15uF; C1812K
D23: 75VWM; SMC
F1: 1812L
IC2: ISO1050DW; SO-16DW
JP1, JP2: MKDS_1,5/2-5MM
L1: MSS1260-274KL_; MSS1260
L2: 820uH; WE-FC_ET
LED1, LED4: GREEN; SML1206
LED2, LED3: RED; SML1206
PCB1: RASPBERRY_PI_B+
R4: 4K7; R1206
R5, R6, R7, R8: 330; R1206
U1: UA78M05CDCY; SOT230P700X180-4N
U$1: REC5-1205SRW/H4/A; DIP24
U$2: MCP2515SO; SO18L
Y1: 16MHz; HC49US

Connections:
3V3: C2.1, C7.1, C8.1, IC2.1 (VCC1), PCB1.1 (3V3), PCB1.17 (3V3), R4.1, R5.1, R6.1, R7.1, R8.1, U$2.18 (VCC)
+5V: C11.1, L1.P$2, PCB1.2 (5V0), PCB1.4 (5V0)
+5V/4: C5.2, C6.1, IC2.16 (VCC2), U1.3 (OUTPUT)
+5V_PRE: L1.P$1, U$1.14 (+VOUT)
+VIN: C10.1, L2.3, U$1.22 (+VIN), U$1.23 (+VIN)
-VIN: C10.2, L2.2 (4), U$1.2 (-VIN), U$1.3 (-VIN)
CANH: IC2.13 (CANH), JP2.1
CANL: IC2.12 (CANL), JP2.2
CS: PCB1.24 (!CE0!/GPIO8), U$2.16 (CS/)
GND: C1.2, C2.2, C3.2, C7.2, C8.2, C11.2, IC2.2 (GND1), IC2.7 (GND1), IC2.8 (GND1), LED1.C, PCB1.6 (GND), PCB1.9 (GND), PCB1.14 (GND), PCB1.20 (GND), PCB1.25 (GND), PCB1.30 (GND), PCB1.34 (GND), PCB1.39 (GND), PCB1.PE_TL (TL), PCB1.PE_TR (TR), U$1.16 (-VOUT), U$2.9 (VSS)
GND-ISO: C4.1, C5.1, C6.2, C9.2, D23.A, IC2.9 (GND2), IC2.10 (GND2), IC2.15 (GND2), JP1.2, L2.1, U1.2 (COMMON_2), U1.4 (COMMON)
INT: LED4.C, PCB1.22 (GEN/6GPIO25), U$2.12 (INT/)
MISO: PCB1.21 (GPIO9/MISO), U$2.15 (SO)
MOSI: PCB1.19 (GPIO10/MOSI), U$2.14 (SI)
unnamed: R4.2, U$2.17 (RESET/)
unnamed: C1.1, U$2.8 (OSC1), Y1.1
unnamed: C3.1, U$2.7 (OSC2), Y1.2
unnamed: F1.P$2 (2), JP1.1
unnamed: LED1.A, R5.2
unnamed: LED2.A, R6.2
unnamed: LED3.A, R7.2
unnamed: LED4.A, R8.2
RX_CAN: IC2.3 (RXD), LED3.C, U$2.2 (RXCAN)
SCK: PCB1.23 (GPIO11/SCLK), U$2.13 (SCK)
TX_CAN: IC2.6 (TXD), LED2.C, U$2.1 (TXCAN)
VCC-ISO: C4.2, C9.1, D23.C, F1.P$1 (1), L2.4 (2), U1.1 (INPUT)

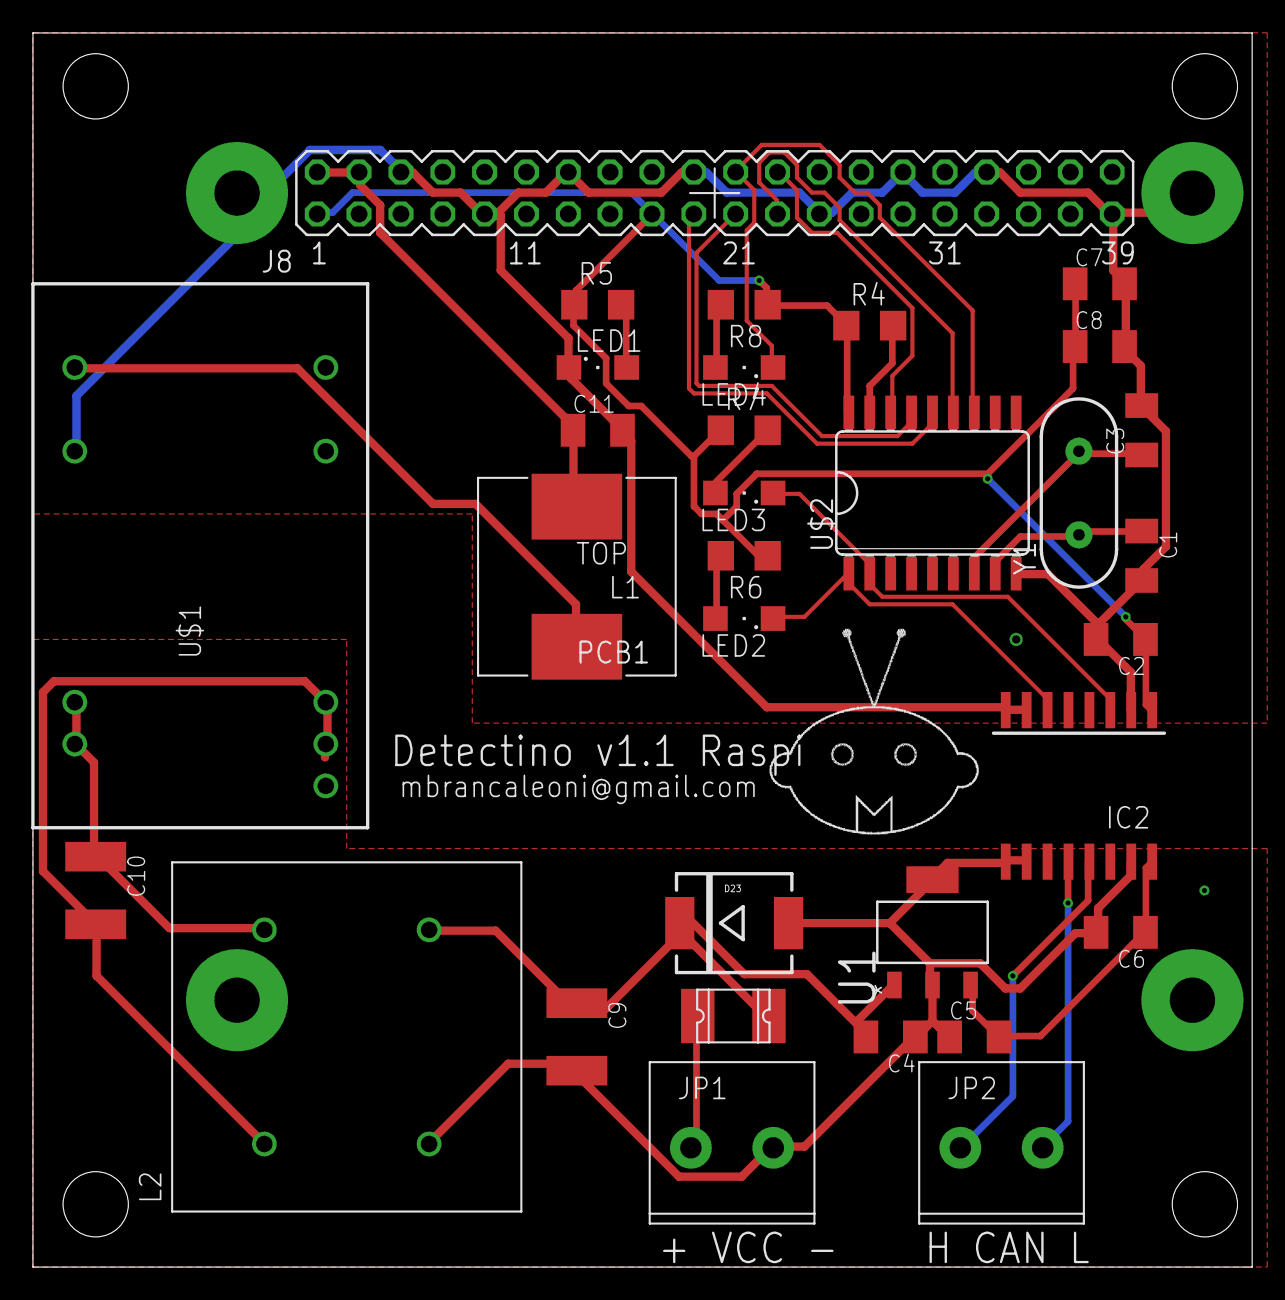
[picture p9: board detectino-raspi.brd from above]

Board: 2 copper layers, 74.0 x 74.9 mm, 33 parts (0 on the bottom side), 26 nets.

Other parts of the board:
U$6: LOGO

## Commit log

2015-10-18 initial import
    [detectino-raspi.brd, detectino-raspi.sch, detectino.brd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]
2017-10-15 kicad files for new board with 16 inputs, 2 relays and 6 open collectors outputs
    [Can_Interface.sch, Digital_IO.sch, Sensors_Inputs.sch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]

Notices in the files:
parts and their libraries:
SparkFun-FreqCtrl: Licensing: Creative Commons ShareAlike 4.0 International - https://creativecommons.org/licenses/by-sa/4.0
